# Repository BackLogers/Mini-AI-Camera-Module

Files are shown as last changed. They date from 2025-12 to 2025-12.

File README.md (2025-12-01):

# Mini AI Camera Module

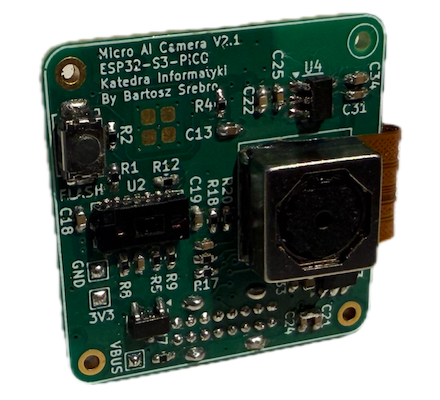
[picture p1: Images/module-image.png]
Mini AI Camera Module (https://github.com/BackLogers/Mini-AI-Camera-Module/tree/main)


## Project Description 

The **Mini AI Camera Module** is a compact platform based on the **ESP32-S3**, combining a standard visible-light camera with a **LiDAR** sensor. The module is designed as a low-cost solution for implementing simple AI algorithms, image recognition, and basic 3D depth perception.

This project includes:
- **OV5640** visible-light camera (5 MP)
- **VL53L5CX** LiDAR camera with an **8×8 pixel** depth map  

*(A future hardware revision is planned to include the **VL53L9CX** sensor featuring a 54×42 pixel resolution.)*

## Key Features

1. **Compact size: 25×25 mm**  
   The module includes mounting holes for easy installation, e.g., in mobile robots.

2. **Two complementary imaging systems**  
   - **OV5640 – 5 MP visible-light camera**  
   - **VL53L5CX – 8×8 pixel LiDAR sensor**

3. **Low production cost**  
   - Uses popular and cost-effective electronic components  
   - PCB designed with simple manufacturing requirements  
   - Complete **JLCPCB** production files included

4. **Ideal for autonomous and IoT projects**  
   Suitable for robotics, autonomous vehicles, perception systems, and IoT devices.

5. **Wireless connectivity**  
   With the ESP32-S3, the module supports:  
   - WiFi  
   - Bluetooth  
   - **ESP-NOW**

6. **Convenient USB and UART interfaces**  
   - Vertical **USB-C** port allows direct mounting to a robot chassis  
   - **SBU1 and SBU2** lines are exposed as **UART**, enabling easy integration with external devices

7. **Easy to use and based on open-source libraries**  
   The project is designed to be simple to integrate and develop with. It relies on well-maintained open-source libraries (including SparkFun drivers) as well as built-in components from the ESP-IDF framework.

8. **Open-source project (Apache 2.0 License)**  
   The entire project is fully open-source and released under the Apache 2.0 license, allowing both personal and commercial use with minimal restrictions.

## Repository Contents

- Technical documentation  
- Schematics and PCB design  
- JLCPCB fabrication files  
- Example firmware for **Arduino**

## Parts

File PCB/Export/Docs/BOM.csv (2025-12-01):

Reference | Value | Datasheet | Footprint | Qty | DNP
AE1 | Antenna_Ceramic | https://www.mouser.pl/ProductDetail/603-ANT3216LL00R2400 | Capacitor_SMD:C_1206_3216Metric | 1
C1 | NC | ~ | Capacitor_SMD:C_0402_1005Metric | 1
C2 | 4.7pF | ~ | Capacitor_SMD:C_0402_1005Metric | 1
C3,C4,C18,C19,C27,C28,C33,L2 | 4.7uF | https://www.mouser.pl/ProductDetail/ABRACON/AOTA-B201610S4R7MT?qs=Imq1NPwxi74%2FXKaZqest4g%3D%3D,~ | Capacitor_SMD:C_0402_1005Metric_Pad0.74x0.62mm_HandSolder,Moje_Footprinty:L_2016 | 8
C5,C8,C9,C12,C13,C26,C29,C30,C34,C35,C37 | 100nF | ~ | Capacitor_SMD:C_0402_1005Metric,Capacitor_SMD:C_0402_1005Metric_Pad0.74x0.62mm_HandSolder | 11
C6,C11 | 1uF | ~ | Capacitor_SMD:C_0402_1005Metric,Capacitor_SMD:C_0402_1005Metric_Pad0.74x0.62mm_HandSolder | 2
C7,C10,C31,C32 | 22uF | ~ | Capacitor_SMD:C_0402_1005Metric,Capacitor_SMD:C_0402_1005Metric_Pad0.74x0.62mm_HandSolder | 4
C15,C21 | 10uF | ~ | Capacitor_SMD:C_0402_1005Metric_Pad0.74x0.62mm_HandSolder | 2
C36 | 15pF | ~ | Capacitor_SMD:C_0402_1005Metric_Pad0.74x0.62mm_HandSolder | 1
D1 | SBR3U40S1F-7 | http://www.vishay.com/docs/88525/1n5817.pdf | Diode_SMD:D_SOD-123 | 1
D2 | ESD5Z5.0 | https://www.onsemi.com/pdf/datasheet/esd5z2.5t1-d.pdf | Diode_SMD:D_SOD-523 | 1
D4 | LED | ~ | LED_SMD:LED_0402_1005Metric_Pad0.77x0.64mm_HandSolder | 1
FB1 | 120R-1.3A | ~ | Resistor_SMD:R_0402_1005Metric_Pad0.72x0.64mm_HandSolder | 1
H1,H2,H3,H4 | MountingHole | ~ | Moje_Footprinty:MountingHole_1.1mm_M1_DIN965_Pad,Moje_Footprinty:MountingHole_1.1mm_M1_No_Pad | 4
J1 | USB_C_Vertical | https://www.lcsc.com/product-detail/USB-Connectors_Hanbo-Electronic-MC-118LD-H65_C6332304.html | Moje_Footprinty:USB_C_Hanbo Electronic MC-118LD-H65 | 1
J2 | Conn_Camera | ~ | Moje_Footprinty:Hirose_FH12-24S-0.5SH_1x24-1MP_P0.50mm_Horizontal_WithCamera_BackSide_Opt1 | 1
L1 | 5.6nH/3.0nH | ~ | Inductor_SMD:L_0402_1005Metric | 1
R1,R2,R3,R8 | 47k | ~ | Resistor_SMD:R_0402_1005Metric_Pad0.72x0.64mm_HandSolder | 4
R4,R5,R10,R11,R15 | 4.7k | ~ | Resistor_SMD:R_0402_1005Metric_Pad0.72x0.64mm_HandSolder | 5
R6,R7 | 5.1k | ~ | Resistor_SMD:R_0402_1005Metric_Pad0.72x0.64mm_HandSolder | 2
R9,R12,R13 | 10k | ~ | Resistor_SMD:R_0402_1005Metric_Pad0.72x0.64mm_HandSolder | 3
SW1 | SW_Reset | ~ | Moje_Footprinty:SW_Push_3.0x4.0mm | 1
SW2 | SW_Flash | ~ | Moje_Footprinty:SW_Push_3.0x4.0mm | 1
TP1 | TestPoint_VIN | ~ | TestPoint:TestPoint_Pad_1.0x1.0mm | 1
TP2 | TestPoint_GND | ~ | TestPoint:TestPoint_Pad_1.0x1.0mm | 1
TP3 | TestPoint_3V3 | ~ | TestPoint:TestPoint_Pad_1.0x1.0mm | 1
U1 | VL53L5CX-Sensor_Distance |  | Moje_Footprinty:ST_VL53L5CX_HandSoldering | 1
U2 | ESP32-S3FH4R2 | https://www.espressif.com/sites/default/files/documentation/esp32-s3_datasheet_en.pdf | Moje_Footprinty:QFN-56-1EP_7x7mm_P0.4mm_EP4x4mm_ThermalVias_ESP32 | 1
U3 | CH213K |  | Package_TO_SOT_SMD:SOT-23 | 1
U5 | RT9193-1V2 |  | Package_TO_SOT_SMD:SOT-23-5 | 1
U6 | RT9193-2V8 |  | Package_TO_SOT_SMD:SOT-23-5 | 1
U7 | AP63203WU | https://www.diodes.com/assets/Datasheets/AP63200-AP63201-AP63203-AP63205.pdf | Package_TO_SOT_SMD:TSOT-23-6 | 1

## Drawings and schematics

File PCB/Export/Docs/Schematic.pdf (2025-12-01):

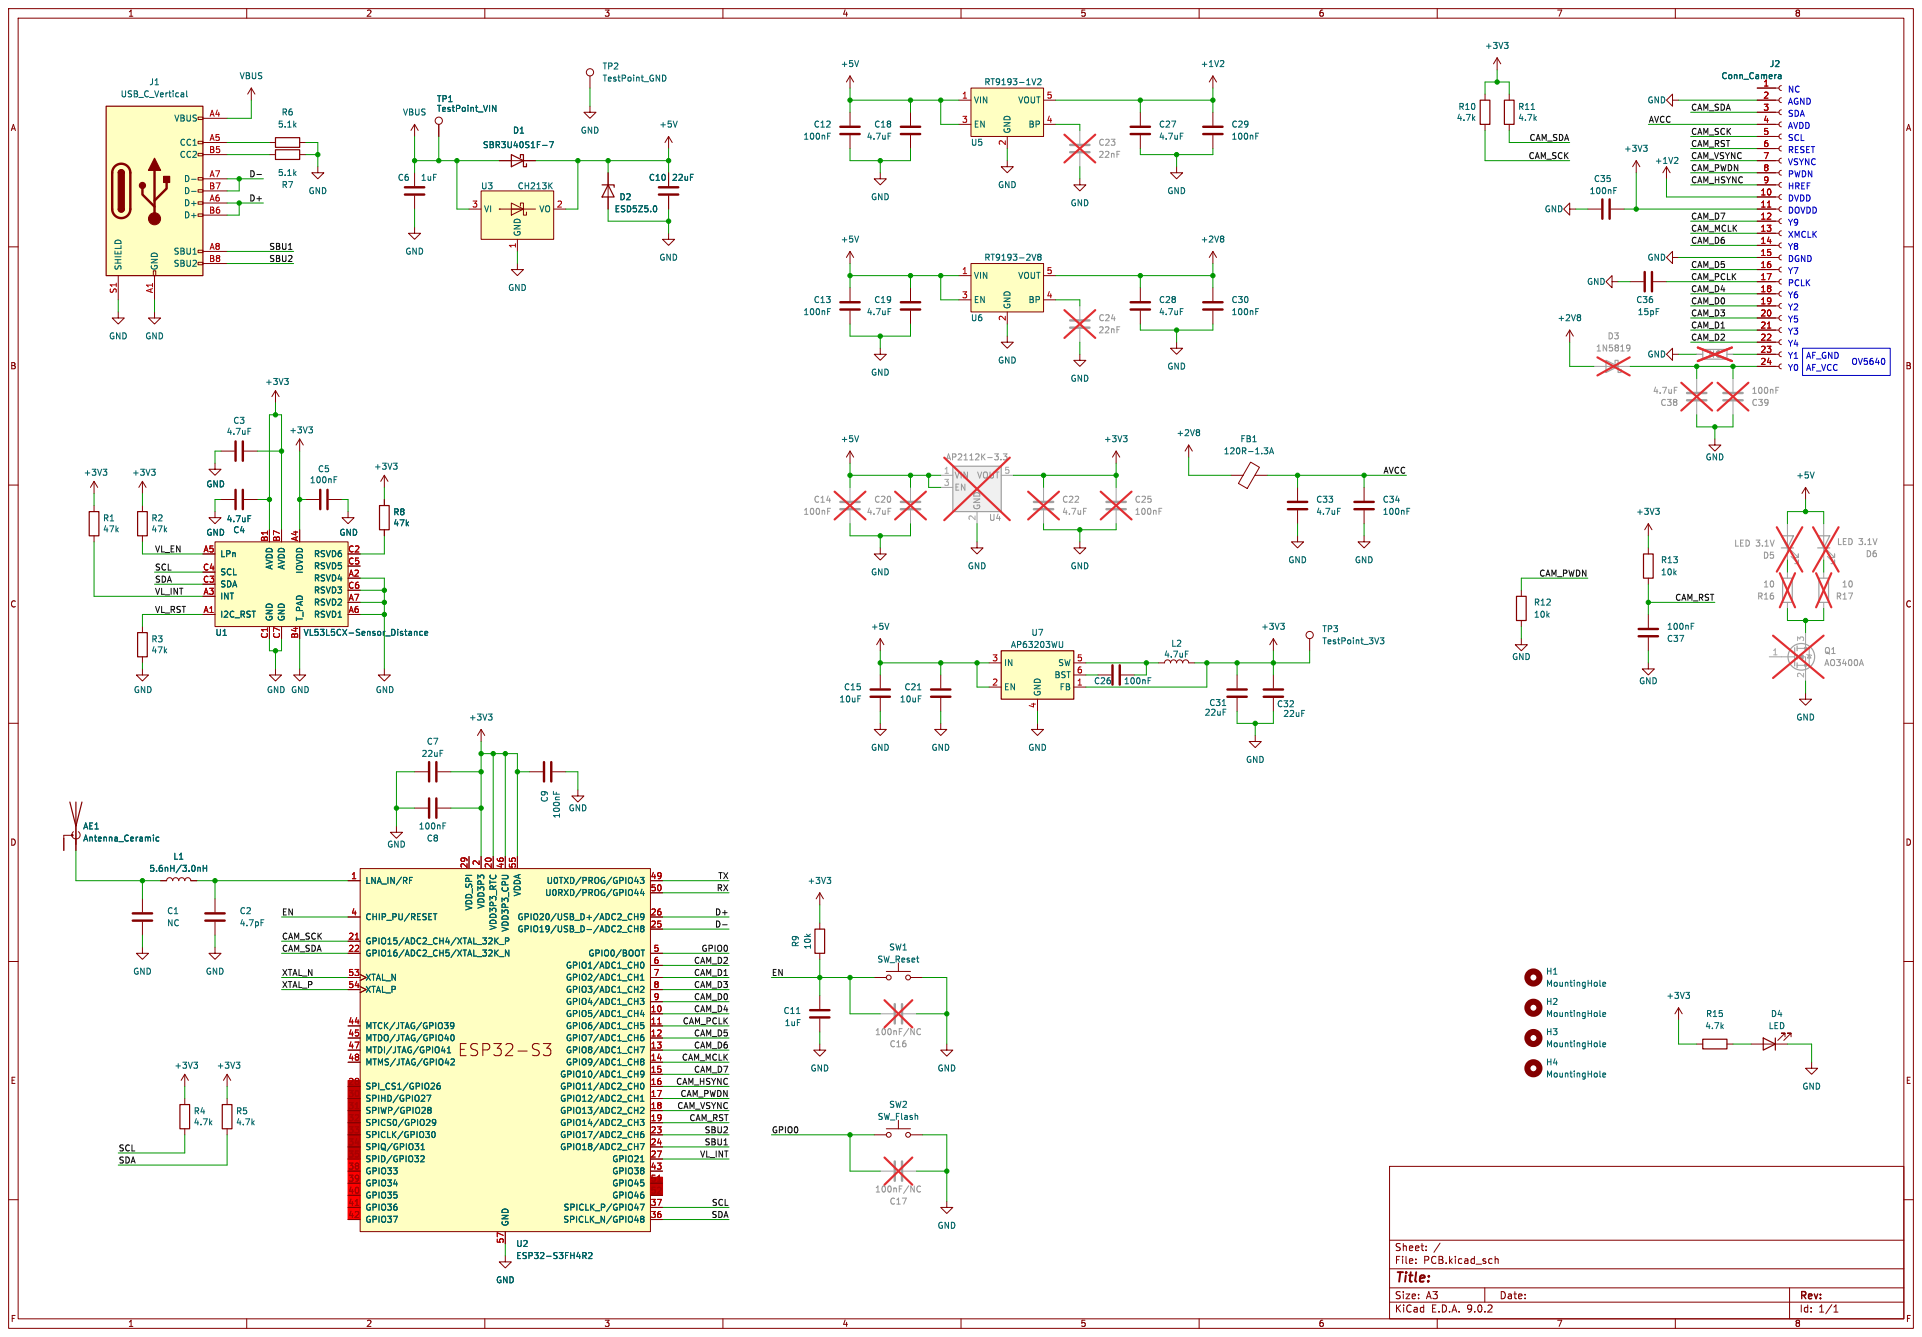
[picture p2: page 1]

4 SW 5 BST 6 FB 1 U7 AP63203WU GND

2 VDD3P3_RTC 20 VDD3P3_CPU 46 GND 57 VDDA 55 U0TXD/PROG/GPIO43 49 U0RXD/PROG/GPIO44 50 GPIO20/USB_D+/ADC2_CH9 26 GPIO19/USB_D-/ADC2_CH8 25 GPIO0/BOOT 5 GPIO1/ADC1_CH0 6 GPIO2/ADC1_CH1 7 GPIO3/ADC1_CH2 8 GPIO4/ADC1_CH3 9 GPIO5/ADC1_CH4 10 GPIO6/ADC1_CH5 11 GPIO7/ADC1_CH6 12 GPIO8/ADC1_CH7 13 GPIO9/ADC1_CH8 14 GPIO10/ADC1_CH9 15 GPIO11/ADC2_CH0 16 GPIO12/ADC2_CH1 17 GPIO13/ADC2_CH2 18 GPIO14/ADC2_CH3 19 GPIO17/ADC2_CH6 23 GPIO18/ADC2_CH7 24 GPIO21 27 GPIO38 43 GPIO45 51 GPIO46 52 U2ESP32-S3FH4R2

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

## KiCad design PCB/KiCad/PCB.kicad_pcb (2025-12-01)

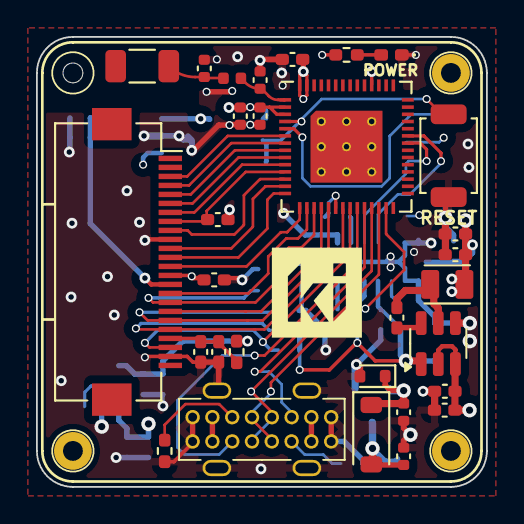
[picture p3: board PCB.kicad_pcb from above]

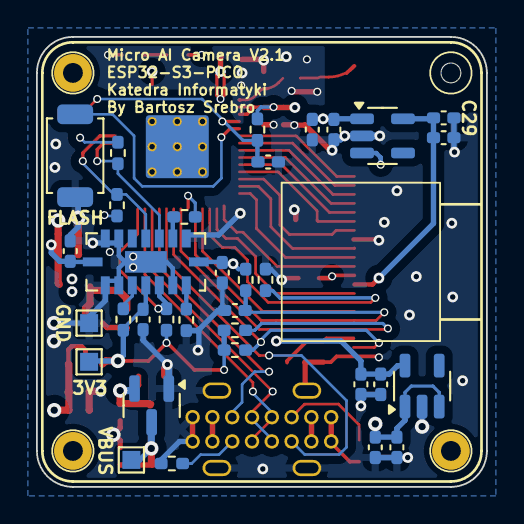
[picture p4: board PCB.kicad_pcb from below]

Board: 4 copper layers, 25.0 x 25.0 mm, 67 parts (33 on the bottom side), 42 nets.

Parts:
AE1: Antenna_Ceramic; C_1206_3216Metric
C1: NC; C_0402_1005Metric
C2: 4.7pF; C_0402_1005Metric
C3, C4, C18, C19, C27, C28, C33: 4.7uF; C_0402_1005Metric_Pad0.74x0.62mm_HandSolder
C5, C9, C12, C13, C26, C29, C30, C34, C35, C37: 100nF; C_0402_1005Metric_Pad0.74x0.62mm_HandSolder
C6: 1uF; C_0402_1005Metric
C7, C10: 22uF; C_0402_1005Metric
C8: 100nF; C_0402_1005Metric
C11: 1uF; C_0402_1005Metric_Pad0.74x0.62mm_HandSolder
C15, C21: 10uF; C_0402_1005Metric_Pad0.74x0.62mm_HandSolder
C31, C32: 22uF; C_0402_1005Metric_Pad0.74x0.62mm_HandSolder
C36: 15pF; C_0402_1005Metric_Pad0.74x0.62mm_HandSolder
D1: SBR3U40S1F-7; D_SOD-123
D2: ESD5Z5.0; D_SOD-523
D4: LED; LED_0402_1005Metric_Pad0.77x0.64mm_HandSolder
FB1: 120R-1.3A; R_0402_1005Metric_Pad0.72x0.64mm_HandSolder
H1: MountingHole; MountingHole_1.1mm_M1_No_Pad
H2, H3, H4: MountingHole; MountingHole_1.1mm_M1_DIN965_Pad
J1: USB_C_Vertical; USB_C_Hanbo Electronic MC-118LD-H65
J2: Conn_Camera; Hirose_FH12-24S-0.5SH_1x24-1MP_P0.50mm_Horizontal_WithCamer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
L1: 5.6nH/3.0nH; L_0402_1005Metric
L2: 4.7uF; L_2016
R1, R2, R3, R8: 47k; R_0402_1005Metric_Pad0.72x0.64mm_HandSolder
R4, R5, R10, R11, R15: 4.7k; R_0402_1005Metric_Pad0.72x0.64mm_HandSolder
R6, R7: 5.1k; R_0402_1005Metric_Pad0.72x0.64mm_HandSolder
R9, R12, R13: 10k; R_0402_1005Metric_Pad0.72x0.64mm_HandSolder
SW1: SW_Reset; SW_Push_3.0x4.0mm
SW2: SW_Flash; SW_Push_3.0x4.0mm
TP1: TestPoint_VIN; TestPoint_Pad_1.0x1.0mm
TP2: TestPoint_GND; TestPoint_Pad_1.0x1.0mm
TP3: TestPoint_3V3; TestPoint_Pad_1.0x1.0mm
U1: VL53L5CX-Sensor_Distance; ST_VL53L5CX_HandSoldering
U2: ESP32-S3FH4R2; QFN-56-1EP_7x7mm_P0.4mm_EP4x4mm_ThermalVias_ESP32
U3: CH213K; SOT-23
U5: RT9193-1V2; SOT-23-5
U6: RT9193-2V8; SOT-23-5
U7: AP63203WU; TSOT-23-6

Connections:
+1V2: C27.1, C29.1, J2.10, U5.5 (VOUT)
+2V8: C28.1, C30.1, FB1.1, U6.5 (VOUT)
+3V3: C3.2, C4.1, C5.1, C7.2, C8.1, C9.2, C31.2, C32.2, C35.2, J2.11, L2.2, R1.2, R2.2, R4.2, R5.2, R8.1, R9.1, R10.2, R11.2, R13.1, R15.1, TP3.1, U1.A4 (IOVDD), U1.B1 (AVDD), U1.B7 (AVDD), U2.2 (VDD3P3), U2.3 (VDD3P3), U2.20 (VDD3P3_RTC), U2.46 (VDD3P3_CPU), U2.55 (VDDA), U2.56 (VDDA), U7.1 (FB)
+5V: C10.2, C12.1, C13.1, C15.1, C18.1, C19.1, C21.1, D1.1 (K), D2.1 (K), U3.2 (VO), U5.1 (VIN), U5.3 (EN), U6.1 (VIN), U6.3 (EN), U7.2 (EN), U7.3 (IN)
/AVCC: C33.1, C34.1, FB1.2, J2.4
/CAM_D0: J2.19, U2.9 (GPIO4/ADC1_CH3)
/CAM_D1: J2.21, U2.7 (GPIO2/ADC1_CH1)
/CAM_D2: J2.22, U2.6 (GPIO1/ADC1_CH0)
/CAM_D3: J2.20, U2.8 (GPIO3/ADC1_CH2)
/CAM_D4: J2.18, U2.10 (GPIO5/ADC1_CH4)
/CAM_D5: J2.16, U2.12 (GPIO7/ADC1_CH6)
/CAM_D6: J2.14, U2.13 (GPIO8/ADC1_CH7)
/CAM_D7: J2.12, U2.15 (GPIO10/ADC1_CH9)
/CAM_HSYNC: J2.9, U2.16 (GPIO11/ADC2_CH0)
/CAM_MCLK: J2.13, U2.14 (GPIO9/ADC1_CH8)
/CAM_PCLK: C36.2, J2.17, U2.11 (GPIO6/ADC1_CH5)
/CAM_PWDN: J2.8, R12.1, U2.17 (GPIO12/ADC2_CH1)
/CAM_RST: C37.2, J2.6, R13.2, U2.19 (GPIO14/ADC2_CH3)
/CAM_SCK: J2.5, R10.1, U2.21 (GPIO15/ADC2_CH4/XTAL_32K_P)
/CAM_SDA: J2.3, R11.1, U2.22 (GPIO16/ADC2_CH5/XTAL_32K_N)
/CAM_VSYNC: J2.7, U2.18 (GPIO13/ADC2_CH2)
/D+: J1.A6 (D+), J1.B6 (D+), U2.26 (GPIO20/USB_D+/ADC2_CH9)
/D-: J1.A7 (D-), J1.B7 (D-), U2.25 (GPIO19/USB_D-/ADC2_CH8)
/EN: C11.2, R9.2, SW1.1, U2.4 (CHIP_PU/RESET)
/GPIO0: SW2.1, U2.5 (GPIO0/BOOT)
/SBU1: J1.A8 (SBU1), U2.24 (GPIO18/ADC2_CH7)
/SBU2: J1.B8 (SBU2), U2.23 (GPIO17/ADC2_CH6)
/SCL: R4.1, U1.C4 (SCL), U2.37 (SPICLK_P/GPIO47)
/SDA: R5.1, U1.C3 (SDA), U2.36 (SPICLK_N/GPIO48)
/VL_EN: R2.1, U1.A5 (LPn)
/VL_INT: R1.1, U1.A3 (INT), U2.27 (GPIO21)
/VL_RST: R3.2, U1.A1 (I2C_RST)
GND: C1.1, C2.2, C3.1, C4.2, C5.2, C6.1, C7.1, C8.2, C9.1, C10.1, C11.1, C12.2, C13.2, C15.2, C18.2, C19.2, C21.2, C27.2, C28.2, C29.2, C30.2, C31.1, C32.1, C33.2, C34.2, C35.1, C36.1, C37.1, D2.2 (A), D4.1 (K), J1.A1 (GND), J1.A12 (GND), J1.B1 (GND), J1.B12 (GND), J1.S1 (SHIELD), J2.2, J2.15, R3.1, R6.2, R7.1, R12.2, SW1.2, SW2.2, TP2.1, U1.A2 (RSVD4), U1.A6 (RSVD1), U1.A7 (RSVD2), U1.B4 (T_PAD), U1.C1 (GND), U1.C6 (RSVD3), U1.C7 (GND), U2.57 (GND), U3.1 (GND), U5.2 (GND), U6.2 (GND), U7.4 (GND)
unnamed: AE1.1 (A), C1.2, L1.1
unnamed: D4.2 (A), R15.2
unnamed: J1.A5 (CC1), R6.1
unnamed: J1.B5 (CC2), R7.2
unnamed: R8.2, U1.C2 (RSVD6)
unnamed: C2.1, L1.2, U2.1 (LNA_IN/RF)
unnamed: C26.1, U7.6 (BST)
unnamed: C26.2, L2.1, U7.5 (SW)
VBUS: C6.2, D1.2 (A), J1.A4 (VBUS), J1.A9 (VBUS), J1.B4 (VBUS), J1.B9 (VBUS), TP1.1, U3.3 (VI)

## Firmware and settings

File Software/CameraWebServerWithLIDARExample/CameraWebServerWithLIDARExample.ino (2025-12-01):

#include "esp_camera.h"
#include <WiFi.h>
#include <Wire.h>
#include <SparkFun_VL53L5CX_Library.h> //http://librarymanager/All#SparkFun_VL53L5CX

SparkFun_VL53L5CX myImager;
VL53L5CX_ResultsData measurementData;

int imageResolution = 0; //Used to pretty print output
int imageWidth = 0; //Used to pretty print output

#define INT_PIN 21 //Connect VL53L5CX INT pin to pin 4 on your microcontroller
volatile bool dataReady = false; //Goes true when interrupt fires

//
// WARNING!!! PSRAM IC required for UXGA resolution and high JPEG quality
//            Ensure ESP32 Wrover Module or other board with PSRAM is selected
//            Partial images will be transmitted if image exceeds buffer size
//
//            You must select partition scheme from the board menu that has at least 3MB APP space.
//            Face Recognition is DISABLED for ESP32 and ESP32-S2, because it takes up from 15
//            seconds to process single frame. Face Detection is ENABLED if PSRAM is enabled as well

// ===================
// Select camera model
// ===================
//#define CAMERA_MODEL_WROVER_KIT // Has PSRAM
//#define CAMERA_MODEL_ESP_EYE  // Has PSRAM
//#define CAMERA_MODEL_ESP32S3_EYE // Has PSRAM
//#define CAMERA_MODEL_M5STACK_PSRAM // Has PSRAM
//#define CAMERA_MODEL_M5STACK_V2_PSRAM // M5Camera version B Has PSRAM
//#define CAMERA_MODEL_M5STACK_WIDE // Has PSRAM
//#define CAMERA_MODEL_M5STACK_ESP32CAM // No PSRAM
//#define CAMERA_MODEL_M5STACK_UNITCAM // No PSRAM
//#define CAMERA_MODEL_M5STACK_CAMS3_UNIT  // Has PSRAM
//#define CAMERA_MODEL_AI_THINKER // Has PSRAM
//#define CAMERA_MODEL_TTGO_T_JOURNAL // No PSRAM
#define CAMERA_MODEL_XIAO_ESP32S3 // Has PSRAM
// ** Espressif Internal Boards **
//#define CAMERA_MODEL_ESP32_CAM_BOARD
//#define CAMERA_MODEL_ESP32S2_CAM_BOARD
//#define CAMERA_MODEL_ESP32S3_CAM_LCD
//#define CAMERA_MODEL_DFRobot_FireBeetle2_ESP32S3 // Has PSRAM
//#define CAMERA_MODEL_DFRobot_Romeo_ESP32S3 // Has PSRAM
#include "camera_pins.h"

// ===========================
// Enter your WiFi credentials
// ===========================
const char *ssid = "SSID";
const char *password = "PASSWORD";

void startCameraServer();
void setupLedFlash(int pin);

void setup() {
  Serial.begin(115200);

  Wire.begin(48,47); //This resets I2C bus to 100kHz
  Wire.setClock(1000000); //Sensor has max I2C freq of 1MHz

  Serial.println("Initializing sensor board. This can take up to 10s. Please wait.");
  if (myImager.begin() == false)
  {
    Serial.println(F("Sensor not found - check your wiring. Freezing"));
    while (1) ;
  }

  myImager.setResolution(8 * 8); //Enable all 64 pads

  imageResolution = myImager.getResolution(); //Query sensor for current resolution - either 4x4 or 8x8
  imageWidth = sqrt(imageResolution); //Calculate printing width

  myImager.setRangingFrequency(15);

  // Attach the interrupt
  attachInterrupt(digitalPinToInterrupt(INT_PIN), interruptRoutine, FALLING);
  Serial.println(F("Interrupt pin configured."));

  myImager.startRanging();

  Serial.setDebugOutput(true);
  Serial.println();

  camera_config_t config;
  config.ledc_channel = LEDC_CHANNEL_0;
  config.ledc_timer = LEDC_TIMER_0;
  config.pin_d0 = Y2_GPIO_NUM;
  config.pin_d1 = Y3_GPIO_NUM;
  config.pin_d2 = Y4_GPIO_NUM;
  config.pin_d3 = Y5_GPIO_NUM;
  config.pin_d4 = Y6_GPIO_NUM;
  config.pin_d5 = Y7_GPIO_NUM;
  config.pin_d6 = Y8_GPIO_NUM;
  config.pin_d7 = Y9_GPIO_NUM;
  config.pin_xclk = XCLK_GPIO_NUM;
  config.pin_pclk = PCLK_GPIO_NUM;
  config.pin_vsync = VSYNC_GPIO_NUM;
  config.pin_href = HREF_GPIO_NUM;
  config.pin_sccb_sda = SIOD_GPIO_NUM;
  config.pin_sccb_scl = SIOC_GPIO_NUM;
  config.pin_pwdn = PWDN_GPIO_NUM;
  config.pin_reset = RESET_GPIO_NUM;
  config.xclk_freq_hz = 8000000; //Max speed at init!
  config.frame_size = FRAMESIZE_UXGA;
  config.pixel_format = PIXFORMAT_JPEG;  // for streaming
  //config.pixel_format = PIXFORMAT_RGB565; // for face detection/recognition
  config.grab_mode = CAMERA_GRAB_WHEN_EMPTY;
  config.fb_location = CAMERA_FB_IN_PSRAM;
  config.jpeg_quality = 12;
  config.fb_count = 1;

  // if PSRAM IC present, init with UXGA resolution and higher JPEG quality
  //                      for larger pre-allocated frame buffer.
  if (config.pixel_format == PIXFORMAT_JPEG) {
    if (psramFound()) {
      config.jpeg_quality = 10;
      config.fb_count = 2;
      config.grab_mode = CAMERA_GRAB_LATEST;
    } else {
      // Limit the frame size when PSRAM is not available
      config.frame_size = FRAMESIZE_SVGA;
      config.fb_location = CAMERA_FB_IN_DRAM;
    }
  } else {
    // Best option for face detection/recognition
    config.frame_size = FRAMESIZE_240X240;
#if CONFIG_IDF_TARGET_ESP32S3
    config.fb_count = 2;
#endif
  }

#if defined(CAMERA_MODEL_ESP_EYE)
  pinMode(13, INPUT_PULLUP);
  pinMode(14, INPUT_PULLUP);
#endif

  // camera init
  esp_err_t err = esp_camera_init(&config);
  if (err != ESP_OK) {
    Serial.printf("Camera init failed with error 0x%x", err);
    return;
  }

  sensor_t *s = esp_camera_sensor_get();
  // initial sensors are flipped vertically and colors are a bit saturated
  if (s->id.PID == OV3660_PID) {
    s->set_vflip(s, 1);        // flip it back
    s->set_brightness(s, 1);   // up the brightness just a bit
    s->set_saturation(s, -2);  // lower the saturation
  }
  // drop down frame size for higher initial frame rate
  if (config.pixel_format == PIXFORMAT_JPEG) {
    s->set_framesize(s, FRAMESIZE_QVGA);
  }

#if defined(CAMERA_MODEL_M5STACK_WIDE) || defined(CAMERA_MODEL_M5STACK_ESP32CAM)
  s->set_vflip(s, 1);
  s->set_hmirror(s, 1);
#endif

#if defined(CAMERA_MODEL_ESP32S3_EYE)
  s->set_vflip(s, 1);
#endif

// Setup LED FLash if LED pin is defined in camera_pins.h
#if defined(LED_GPIO_NUM)
  setupLedFlash(LED_GPIO_NUM);
#endif

  WiFi.begin(ssid, password);
  WiFi.setSleep(false);

  Serial.print("WiFi connecting");
  while (WiFi.status() != WL_CONNECTED) {
    delay(500);
    Serial.print(".");
  }
  Serial.println("");
  Serial.println("WiFi connected");

  // For AP mode
  // WiFi.softAP("TESTABC","123456789");
  // WiFi.setSleep(false);

  startCameraServer();

  Serial.print("Camera Ready! Use 'http://");
  Serial.print(WiFi.localIP());
  Serial.println("' to connect");
}

void loop() {
  //ISR will let us know when new data is ready
  if (dataReady == true)
  {
    dataReady = false;

    if (myImager.getRangingData(&measurementData)) //Read distance data into array
    {
      //The ST library returns the data transposed from zone mapping shown in datasheet
      //Pretty-print data with increasing y, decreasing x to reflect reality
      for (int y = 0 ; y <= imageWidth * (imageWidth - 1) ; y += imageWidth)
      {
        for (int x = imageWidth - 1 ; x >= 0 ; x--)
        {
          Serial.print("\t");
          Serial.print(measurementData.distance_mm[x + y]);
        }
        Serial.println();
      }
      Serial.println();
    }
  }

}

void interruptRoutine()
{
  // Just set the flag that we have updated data and return from the ISR
  dataReady = true;
}

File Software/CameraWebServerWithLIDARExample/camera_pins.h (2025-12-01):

#if defined(CAMERA_MODEL_WROVER_KIT)
#define PWDN_GPIO_NUM  -1
#define RESET_GPIO_NUM -1
#define XCLK_GPIO_NUM  21
#define SIOD_GPIO_NUM  26
#define SIOC_GPIO_NUM  27

#define Y9_GPIO_NUM    35
#define Y8_GPIO_NUM    34
#define Y7_GPIO_NUM    39
#define Y6_GPIO_NUM    36
#define Y5_GPIO_NUM    19
#define Y4_GPIO_NUM    18
#define Y3_GPIO_NUM    5
#define Y2_GPIO_NUM    4
#define VSYNC_GPIO_NUM 25
#define HREF_GPIO_NUM  23
#define PCLK_GPIO_NUM  22

#elif defined(CAMERA_MODEL_ESP_EYE)
#define PWDN_GPIO_NUM  -1
#define RESET_GPIO_NUM -1
#define XCLK_GPIO_NUM  4
#define SIOD_GPIO_NUM  18
#define SIOC_GPIO_NUM  23

#define Y9_GPIO_NUM    36
#define Y8_GPIO_NUM    37
#define Y7_GPIO_NUM    38
#define Y6_GPIO_NUM    39
#define Y5_GPIO_NUM    35
#define Y4_GPIO_NUM    14
#define Y3_GPIO_NUM    13
#define Y2_GPIO_NUM    34
#define VSYNC_GPIO_NUM 5
#define HREF_GPIO_NUM  27
#define PCLK_GPIO_NUM  25

#define LED_GPIO_NUM 22

#elif defined(CAMERA_MODEL_M5STACK_PSRAM)
#define PWDN_GPIO_NUM  -1
#define RESET_GPIO_NUM 15
#define XCLK_GPIO_NUM  27
#define SIOD_GPIO_NUM  25
#define SIOC_GPIO_NUM  23

#define Y9_GPIO_NUM    19
#define Y8_GPIO_NUM    36
#define Y7_GPIO_NUM    18
#define Y6_GPIO_NUM    39
#define Y5_GPIO_NUM    5
#define Y4_GPIO_NUM    34
#define Y3_GPIO_NUM    35
#define Y2_GPIO_NUM    32
#define VSYNC_GPIO_NUM 22
#define HREF_GPIO_NUM  26
#define PCLK_GPIO_NUM  21

#elif defined(CAMERA_MODEL_M5STACK_V2_PSRAM)
#define PWDN_GPIO_NUM  -1
#define RESET_GPIO_NUM 15
#define XCLK_GPIO_NUM  27
#define SIOD_GPIO_NUM  22
#define SIOC_GPIO_NUM  23

#define Y9_GPIO_NUM    19
#define Y8_GPIO_NUM    36
#define Y7_GPIO_NUM    18
#define Y6_GPIO_NUM    39
#define Y5_GPIO_NUM    5
#define Y4_GPIO_NUM    34
#define Y3_GPIO_NUM    35
#define Y2_GPIO_NUM    32
#define VSYNC_GPIO_NUM 25
#define HREF_GPIO_NUM  26
#define PCLK_GPIO_NUM  21

#elif defined(CAMERA_MODEL_M5STACK_WIDE)
#define PWDN_GPIO_NUM  -1
#define RESET_GPIO_NUM 15
#define XCLK_GPIO_NUM  27
#define SIOD_GPIO_NUM  22
#define SIOC_GPIO_NUM  23

#define Y9_GPIO_NUM    19
#define Y8_GPIO_NUM    36
#define Y7_GPIO_NUM    18
#define Y6_GPIO_NUM    39
#define Y5_GPIO_NUM    5
#define Y4_GPIO_NUM    34
#define Y3_GPIO_NUM    35
#define Y2_GPIO_NUM    32
#define VSYNC_GPIO_NUM 25
#define HREF_GPIO_NUM  26
#define PCLK_GPIO_NUM  21

#define LED_GPIO_NUM 2

#elif defined(CAMERA_MODEL_M5STACK_ESP32CAM)
#define PWDN_GPIO_NUM  -1
#define RESET_GPIO_NUM 15
#define XCLK_GPIO_NUM  27
#define SIOD_GPIO_NUM  25
#define SIOC_GPIO_NUM  23

#define Y9_GPIO_NUM    19
#define Y8_GPIO_NUM    36
#define Y7_GPIO_NUM    18
#define Y6_GPIO_NUM    39
#define Y5_GPIO_NUM    5
#define Y4_GPIO_NUM    34
#define Y3_GPIO_NUM    35
#define Y2_GPIO_NUM    17
#define VSYNC_GPIO_NUM 22
#define HREF_GPIO_NUM  26
#define PCLK_GPIO_NUM  21

#elif defined(CAMERA_MODEL_M5STACK_UNITCAM)
#define PWDN_GPIO_NUM  -1
#define RESET_GPIO_NUM 15
#define XCLK_GPIO_NUM  27
#define SIOD_GPIO_NUM  25
#define SIOC_GPIO_NUM  23

#define Y9_GPIO_NUM    19
#define Y8_GPIO_NUM    36
#define Y7_GPIO_NUM    18
#define Y6_GPIO_NUM    39
#define Y5_GPIO_NUM    5
#define Y4_GPIO_NUM    34
#define Y3_GPIO_NUM    35
#define Y2_GPIO_NUM    32
#define VSYNC_GPIO_NUM 22
#define HREF_GPIO_NUM  26
#define PCLK_GPIO_NUM  21

#elif defined(CAMERA_MODEL_M5STACK_CAMS3_UNIT)
#define PWDN_GPIO_NUM  -1
#define RESET_GPIO_NUM 21
#define XCLK_GPIO_NUM  11
#define SIOD_GPIO_NUM  17
#define SIOC_GPIO_NUM  41

#define Y9_GPIO_NUM    13
#define Y8_GPIO_NUM    4
#define Y7_GPIO_NUM    10
#define Y6_GPIO_NUM    5
#define Y5_GPIO_NUM    7
#define Y4_GPIO_NUM    16
#define Y3_GPIO_NUM    15
#define Y2_GPIO_NUM    6
#define VSYNC_GPIO_NUM 42
#define HREF_GPIO_NUM  18
#define PCLK_GPIO_NUM  12

#define LED_GPIO_NUM 14

#elif defined(CAMERA_MODEL_AI_THINKER)
#define PWDN_GPIO_NUM  32
#define RESET_GPIO_NUM -1
#define XCLK_GPIO_NUM  0
#define SIOD_GPIO_NUM  26
#define SIOC_GPIO_NUM  27

#define Y9_GPIO_NUM    35
#define Y8_GPIO_NUM    34
#define Y7_GPIO_NUM    39
#define Y6_GPIO_NUM    36
#define Y5_GPIO_NUM    21
#define Y4_GPIO_NUM    19
#define Y3_GPIO_NUM    18
#define Y2_GPIO_NUM    5
#define VSYNC_GPIO_NUM 25
#define HREF_GPIO_NUM  23
#define PCLK_GPIO_NUM  22

// 4 for flash led or 33 for normal led
#define LED_GPIO_NUM   4

#elif defined(CAMERA_MODEL_TTGO_T_JOURNAL)
#define PWDN_GPIO_NUM  0
#define RESET_GPIO_NUM 15
#define XCLK_GPIO_NUM  27
#define SIOD_GPIO_NUM  25
#define SIOC_GPIO_NUM  23

#define Y9_GPIO_NUM    19
#define Y8_GPIO_NUM    36
#define Y7_GPIO_NUM    18
#define Y6_GPIO_NUM    39
#define Y5_GPIO_NUM    5
#define Y4_GPIO_NUM    34
#define Y3_GPIO_NUM    35
#define Y2_GPIO_NUM    17
#define VSYNC_GPIO_NUM 22
#define HREF_GPIO_NUM  26
#define PCLK_GPIO_NUM  21

#elif defined(CAMERA_MODEL_XIAO_ESP32S3)
#define PWDN_GPIO_NUM  12
#define RESET_GPIO_NUM 14
#define XCLK_GPIO_NUM 9
#define SIOD_GPIO_NUM  16
#define SIOC_GPIO_NUM  15
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
